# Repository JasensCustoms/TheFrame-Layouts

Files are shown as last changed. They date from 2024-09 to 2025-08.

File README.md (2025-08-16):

# TheFrame-Layouts
Layouts for JasensCustoms.com - The Frame Fight Stick

All Layouts are provided either by JasensCustoms.com or a member of the community. These are provided as-is under the GNU Public License V3.0.

# The Frame is by JasensCustoms.com - A fight stick maker since 2012.

What is The Frame? The Frame is our take on the plexi fight stick craze that has taken the Fighting Game Community by storm over the last few years. This combination Acrylic and Machined Aluminum case is not like the rest. 

jasenscustoms-theframe-chassis-1

Some Measurements that you may find useful:

- The distance between the USB Mount Center and the 24.1mm holes on either side is 60mm.



- The distance between each hole on the front is 30mm.



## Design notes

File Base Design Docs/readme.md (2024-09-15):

Welcome to THE FRAME design guide, contained within is all the important details you need for designing your custom Top Panel for THE FRAME. The files provided are for non-commercial use only. Please use them to design your layout and top panel to fit onto your new FRAME. You can submit any of the following file formats for custom cut top panels:

* DXF
* AI
* SVG

On each piece there are mounting holes and some 24mm holes for buttons. Please take the follow into consideration:

Do not remove any mounting holes (the small ones) from the side panel plexi templates.
Do not move any mounting holes. If you move them, your plexi will not attach to your FRAME properly.
You may remove the center mounting holes on the top and bottom panels if you want.
On the side plexi pieces, any of the 24mm holes can be removed if you do not intend on using those cutouts. By removing them the plexi will cover up and hide unused holes.
You can make your top panel and bottom panels larger than your FRAME and have overhang - creating some cool shapes and possibilities for your FRAME. If you add a significant amount of overhang, you may want to consider using some 51mm long support hardware to prevent flexing. There are a lot of creative ways to do this from 3D printed parts to aluminum extrusion. Just keep in mind you will need to provide mounting hole cutouts on your plexi (top, bottom, and inner pieces) to ensure you have a place to feed non-standard hardware.

**The Top and Bottom Panel has two layers.**

The outermost layer is 1.5mm and can be done with printed plexi or any of our standard colored plexi available.

The inner layer is 5mm and will be done with clear, black, or white acrylic based on your choice.

**Top Outermost layer (1.5mm):**

1. Place your buttons and joystick in an arrangement that makes sense for you. You have complete control here. Keep your layout inside of the red lines dashed lines to ensure your buttons will not hit the FRAME. You must ensure all required mounting hardware is accounted for. We will not add or alter files submitted. We cut what you send.
   
3. The Blue Dashed lines represent how far the average 24mm button will extend into the case. You can get close to these if you need to, just be advised that wiring may get tight in those areas.
   
4. If you do not want to add countersinking to the inner layer for lever builds, please ensure your mounting hardware holes for the lever you are using is on the top outer layer.
Ensure you keep the M4 mounting holes in tact on the outermost layer per the above guidelines.

The Fream Safe Area Explainer

**Top Inner Layer (5mm):**

1. Duplicate all of your cuts from the outermost layer to this inner layer.
2. You will want to create offset cuts for all of your buttons. 6.5mm is too thick for non screw in buttons to latch onto. I find that using a 40mm hole for 30mm buttons on the inner panel is sufficient for snap ins. 45mm is great for screw in buttons. (36mm for smaller 24mm buttons). You can use the centers of your top layer holes to do ensure they are perfectly aligned. Once you create them all, you can remove the button cutouts on the inner layer they won't be needed.
3. You do not and should not create offsets for any mounting hardware on this layer.
4. For a nominal fee we will countersink lever mounting hardware on your inner panel using a drill press. This is done after its laser cut to ensure perfect placement.

Example of Top Layers

This a perfect inner and outer layer. There are no extra cut lines on the inner layer. The customer used the pathfinder tool in illustrator to remove overlapping cut lines (or a power trim tool in Solidworks) to create one smooth contour cut for the inner panel. They are larger than the button holes to allow snap-ins and screw-ins to properly hold onto the 1,5mm top.

Not a good setup for top layers

This is not per the design guide. The inner and outer layers are the exact same. You will not have a solid connection with snap-ins and they may pop out. Screw-ins may work, but they wont have enough threads engaged to stay tight long term. Fix the inner layer.

**The Bottom Panel - Inner and Outer pieces**

These should be mechanically identical. If you make the bottom a different and larger shape than the rounded rectangle that is standard, just ensure both are the same. If you only submit one file for the bottom, we will cut both the 1.5mm and 5mm pieces the same. If you have a special need for the inner panel to create additional clearance, its OK to put cutlines on the inner panel. 

**Resources**

* SlagCoin - the most popular arcade layouts. http://www.slagcoin.com
* Sanwa JLF Mounting Points: 84mm x 40mm rectangle. One hole in each corner. Center hole is 24mm.
* #6-32 screw diameter: 3.51mm - use 3.6mm to be safe.
* M4 screw diameter: 4mm (metric is great) - use 4.2mm to be safe.
* 30mm buttons: use 30.1 - 30.2mm to be safe. Using an exact 30 is OK but may add stress to the body.
* 24mm buttons: use 24.1 - 24.1mm to be safe. Using and exact 24 is OK but may add stress to the body.

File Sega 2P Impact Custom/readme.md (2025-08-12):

Overszied Frame Layout (edges overhang the case by 15mm all the way around) with a custom shape requested by the customer. Features Sega 2P layout with impact button and second 24mm button at the top. Features an OLED screen mount on inner panel. Also inner cutout has a larger opening to install an LED ring (50mm diameter).

https://github.com/JasensCustoms/TheFrame-Layouts/blob/main/Sega%202P%20Impact%20Custom/customsega2P.png

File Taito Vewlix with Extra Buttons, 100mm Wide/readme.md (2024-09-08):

# Files By JasensCustoms.com
+ Created for a customer, SPAAAACE! in our discord server. Posted with their permission.
  
# Top Panel 1.5mm Outer Plexi Panel
+	The Taito vewlix layout with 100mm between the K1 button and lever
+	Main Button holes are 30mm buttons
+	A standard Japanese lever size hole on this top layer
+	A row of three 24mm buttons above the standard 30mm vewlix buttons. I’ve attached a photo as an example of the layout of these buttons

# Top Panel 5mm Inner Plexi Panel

+	Enough room underneath the buttons to accommodate screw-in buttons
+	A Korean lever-sized hole (35.1mm) for the joystick plus all mounting holes for both JP and KR levers
+	The same 7.5mm overhang on the left and right, with 2.5 mm on top and bottom. 

# Bottom Panel 5mm Inner Plexi Panel

+	A 100mm x 100mm cutout centered on the Joystick Lever to support deep Korean levers.

# Panel Size Changes

+	A 7.5mm overhang on the left and right edges, and a 2.5mm overhang on the top and bottom edges (to make the lever a little wider without getting much taller).

# Files Included
+ Top and Bottom Plexi in PSD for generating Art
+ Top and Bottom Plexi (inner and outer layers) in AI and DXF Files for remixes



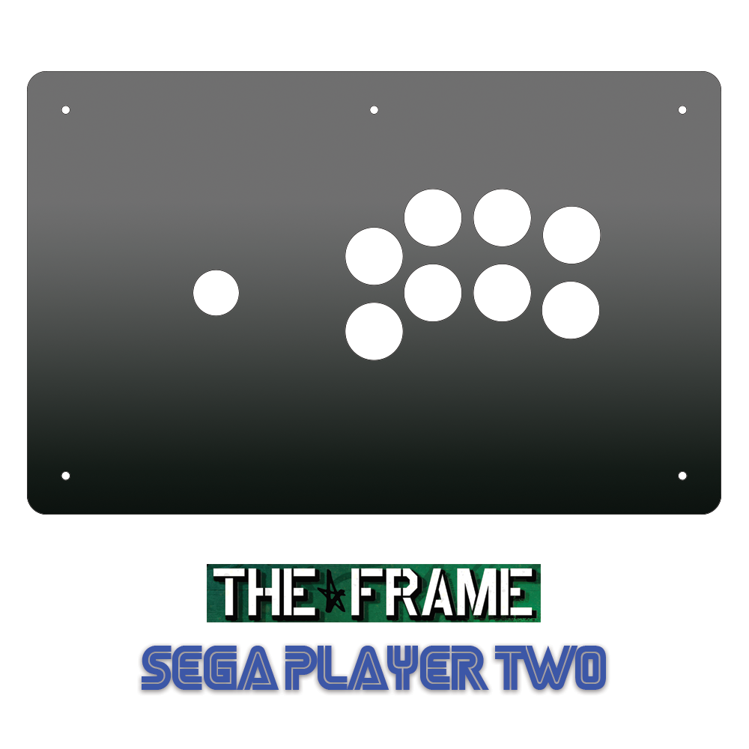
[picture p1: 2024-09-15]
Sega Player 2/Image Card.png

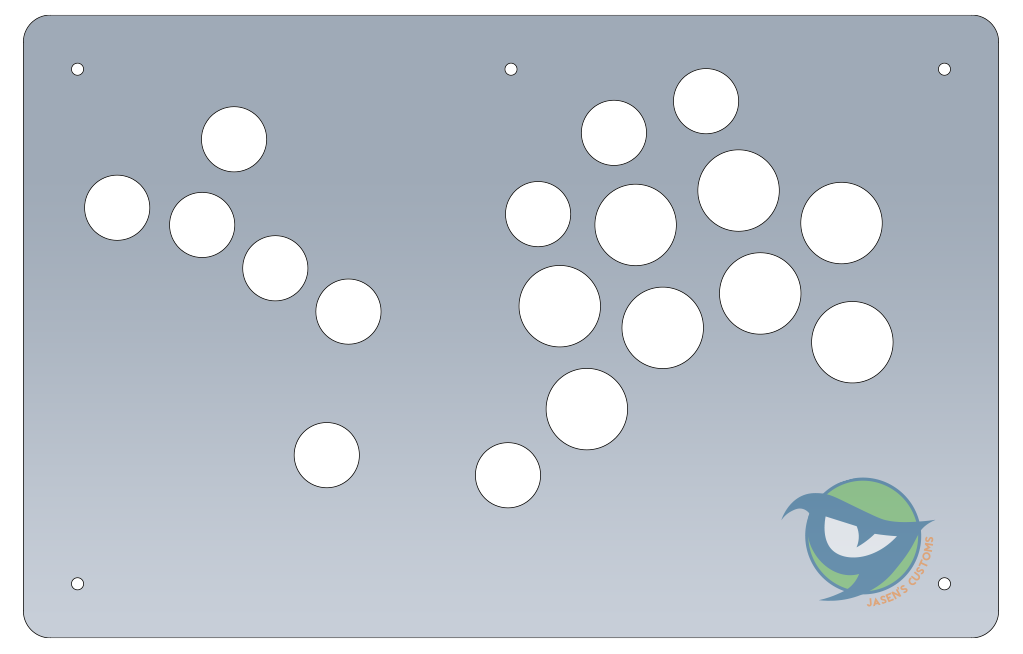
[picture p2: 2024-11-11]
Custom ABC KH Edition/CustomABC-KH.png

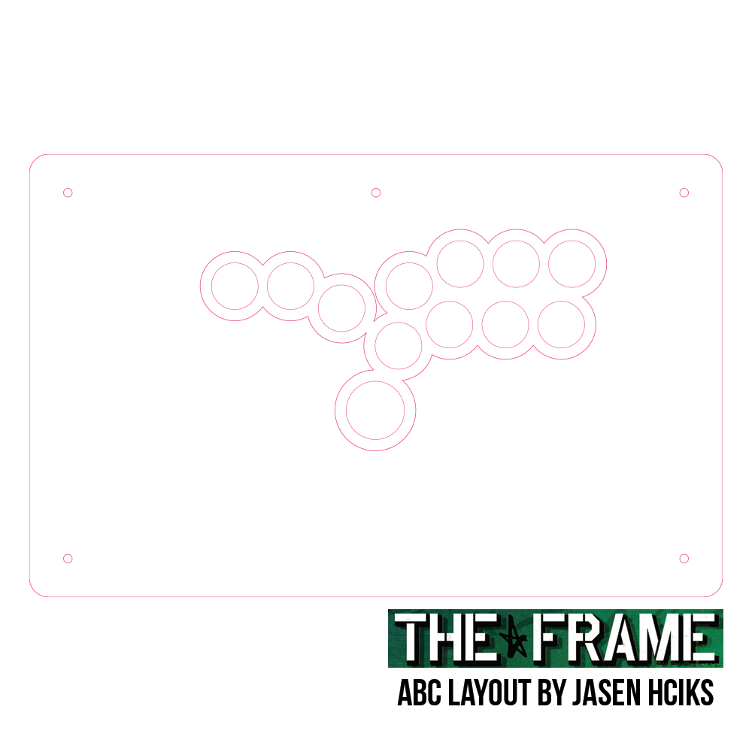
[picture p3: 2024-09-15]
All Button Controller/JasenHicks-ABC.png

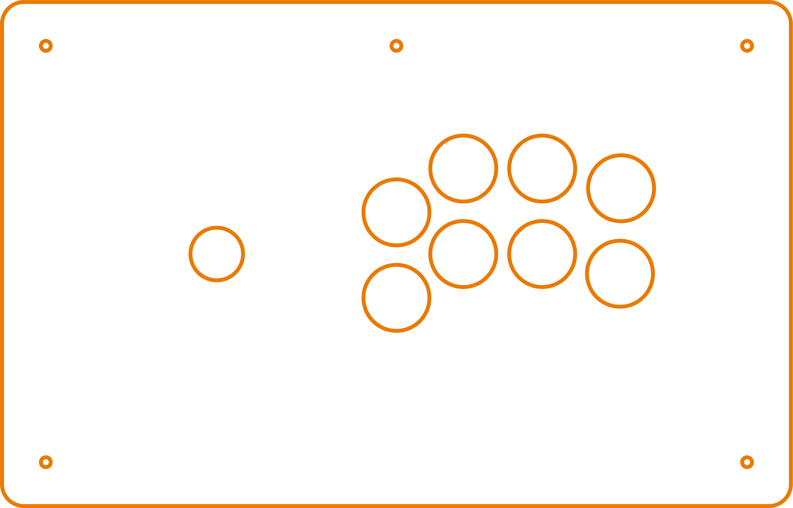
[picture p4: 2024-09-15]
Sega Player 2/JasensCustoms-TheFrame-Sega2P-82mm-Wide-OUTTER.png

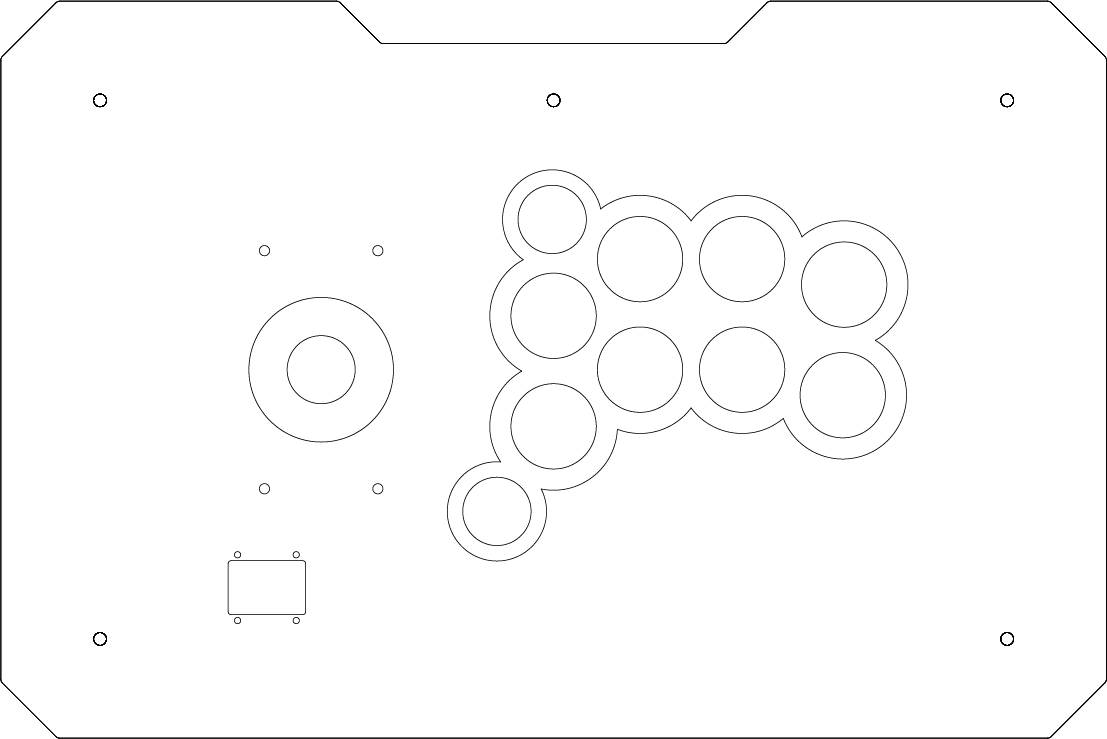
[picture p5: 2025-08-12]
Sega 2P Impact Custom/customsega2P.png

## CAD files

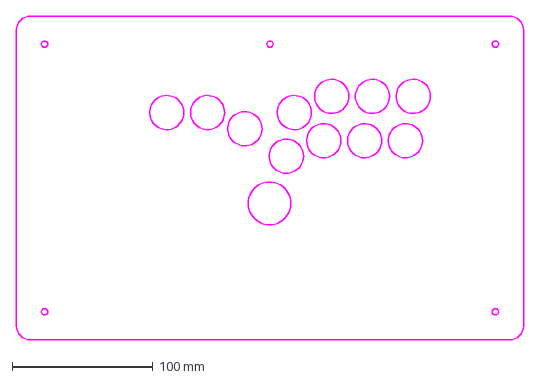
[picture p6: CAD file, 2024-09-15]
All Button Controller/JasensCustoms-ABC-Outermost.dxf
360.0 x 230.0 mm

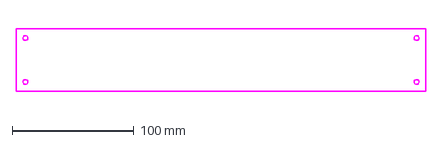
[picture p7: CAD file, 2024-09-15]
Base Design Docs/TheFrame-Back.dxf
336.0 x 51.0 mm

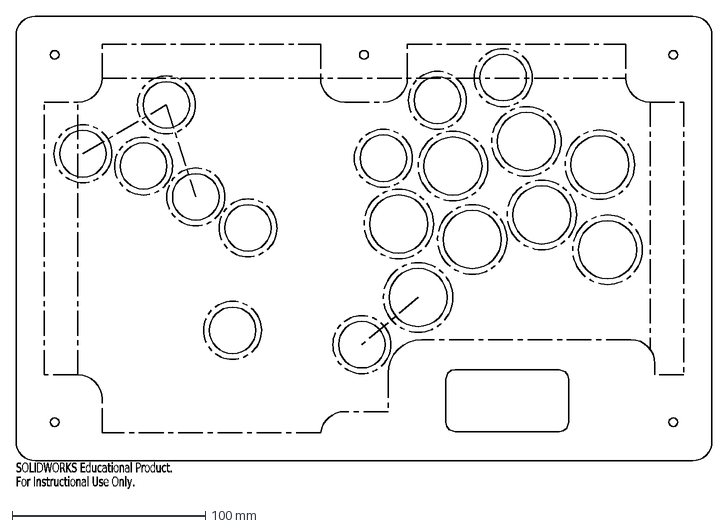
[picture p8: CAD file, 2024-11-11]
Custom ABC KH Edition/JasensCustoms-TheFrame-ABC-KH-OUTER.DXF
SOLIDWORKS Educational Product.
For Instructional Use Only.

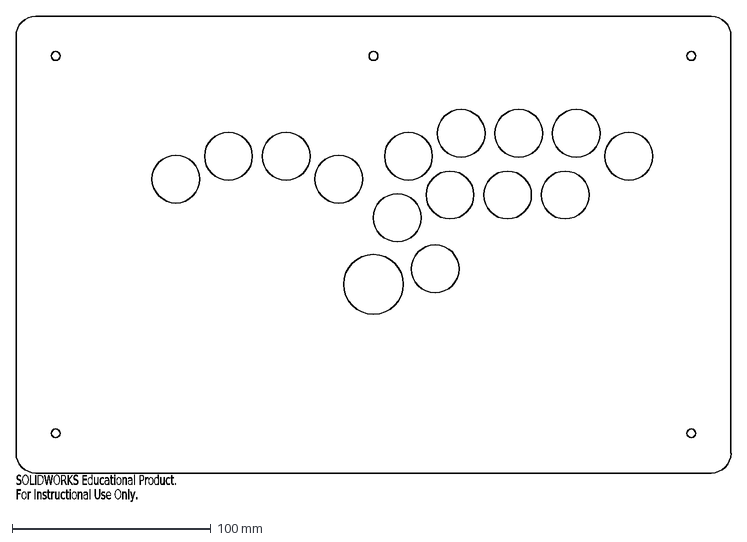
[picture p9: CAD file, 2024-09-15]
Daigo x Rageous X All Button Modern/JasensCustoms-TheFrame-DaigoInspiredABC-OUTER.DXF
SOLIDWORKS Educational Product.
For Instructional Use Only.

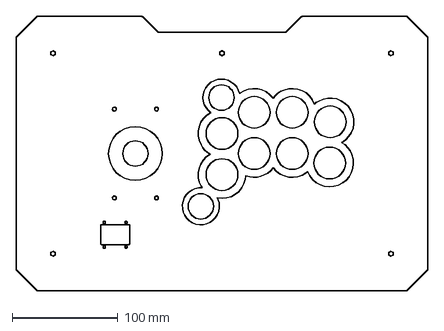
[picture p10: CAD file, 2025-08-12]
Sega 2P Impact Custom/2919 - Robert B - Layout BOTTOM.dxf
390.0 x 260.0 mm

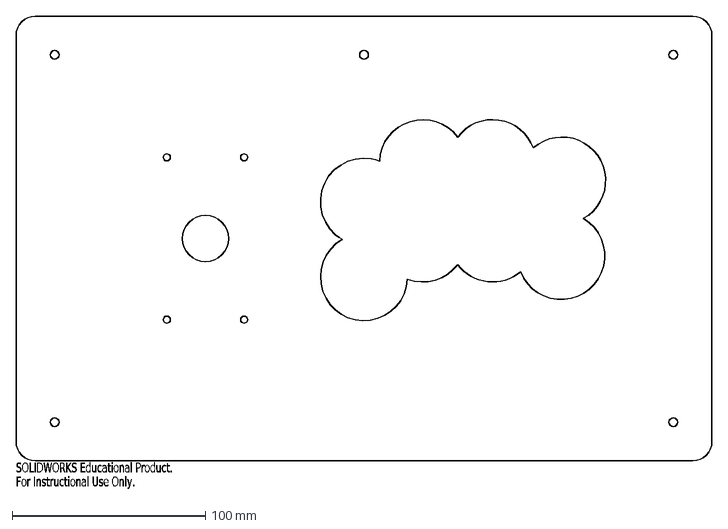
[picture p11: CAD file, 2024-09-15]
Sega Player 2/JasensCustoms-TheFrame-Sega2P-82mm-Wide-INNER.DXF
SOLIDWORKS Educational Product.
For Instructional Use Only.

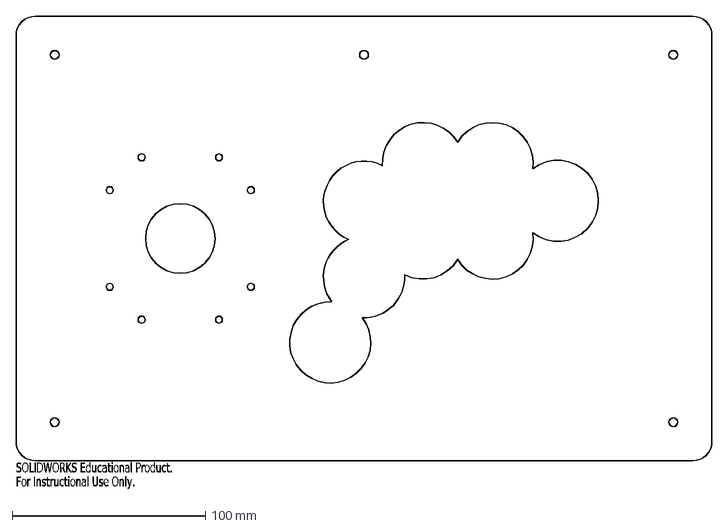
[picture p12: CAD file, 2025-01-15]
SP26M Layout/JasensCustoms-TheFrame-SP26M-Inner.DXF
SOLIDWORKS Educational Product.
For Instructional Use Only.

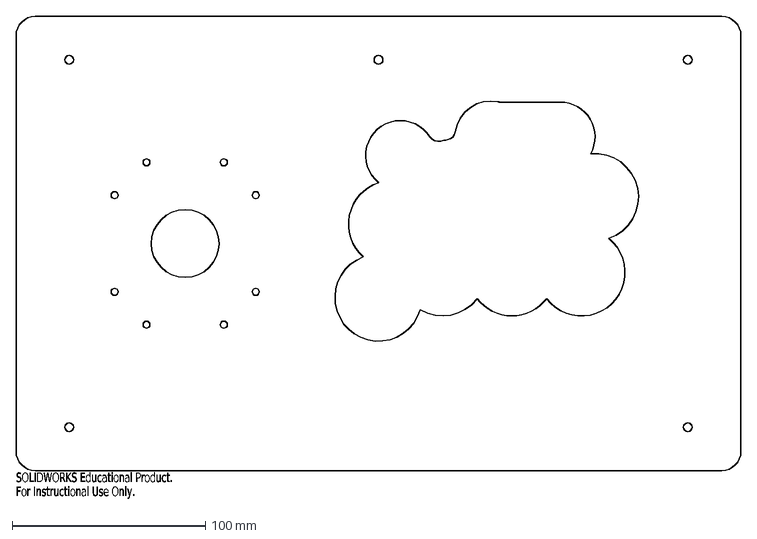
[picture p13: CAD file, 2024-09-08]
Taito Vewlix with Extra Buttons, 100mm Wide/JasensCustoms-TheFrame-TaitoVewlix Base - 100mm-Wide - Top 5.6mm.DXF
SOLIDWORKS Educational Product.
For Instructional Use Only.

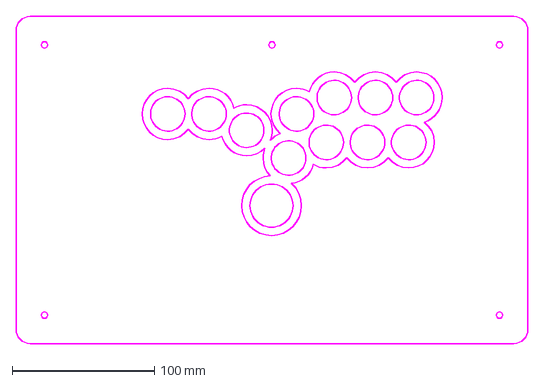
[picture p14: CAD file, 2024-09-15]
All Button Controller/JasensCustoms-ABC-Innermost.dxf
360.0 x 230.0 mm

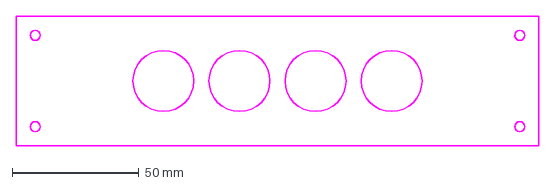
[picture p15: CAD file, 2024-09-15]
Base Design Docs/TheFrame-Short Side.dxf
206.0 x 51.0 mm

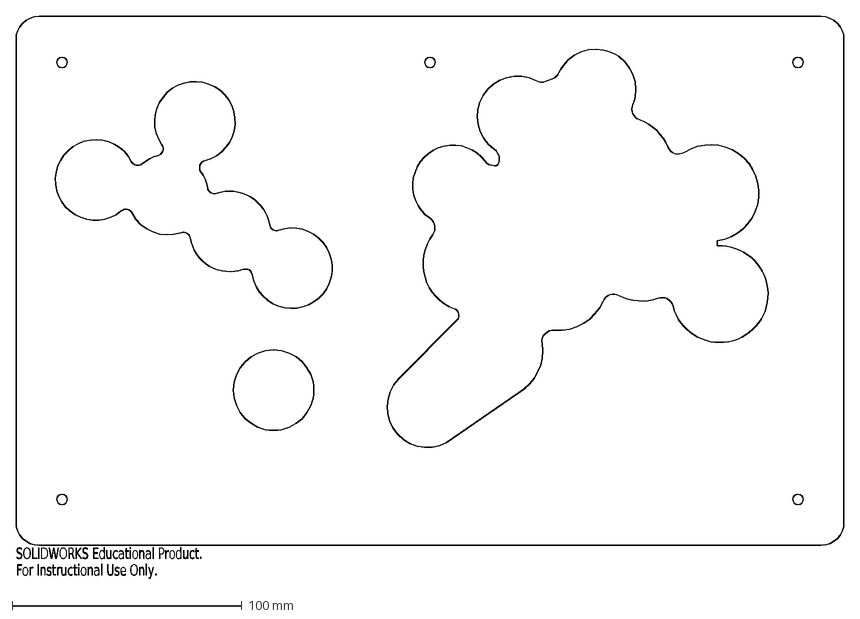
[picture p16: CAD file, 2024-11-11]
Custom ABC KH Edition/JasensCustoms-TheFrame-ABC-KH-INNER.DXF
SOLIDWORKS Educational Product.
For Instructional Use Only.

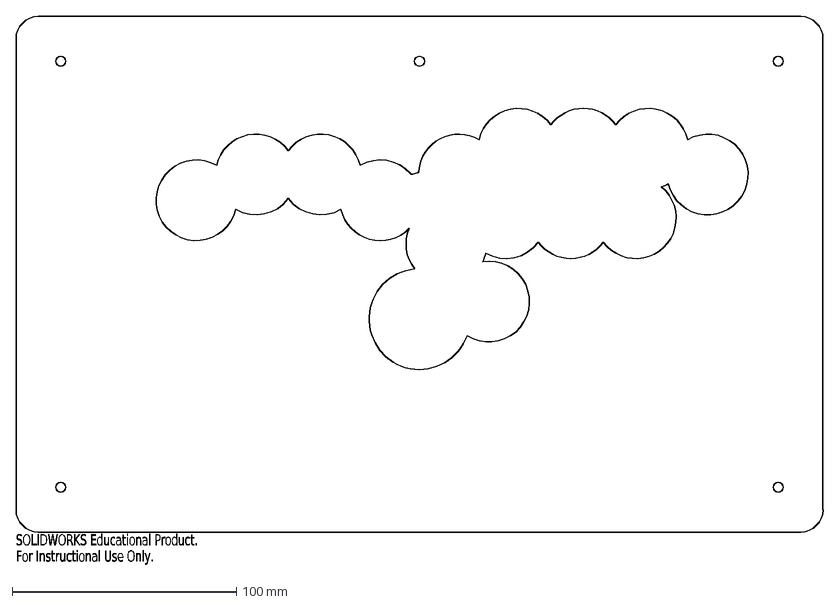
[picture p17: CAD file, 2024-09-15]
Daigo x Rageous X All Button Modern/JasensCustoms-TheFrame-DaigoInspiredABC-INNER.DXF
SOLIDWORKS Educational Product.
For Instructional Use Only.

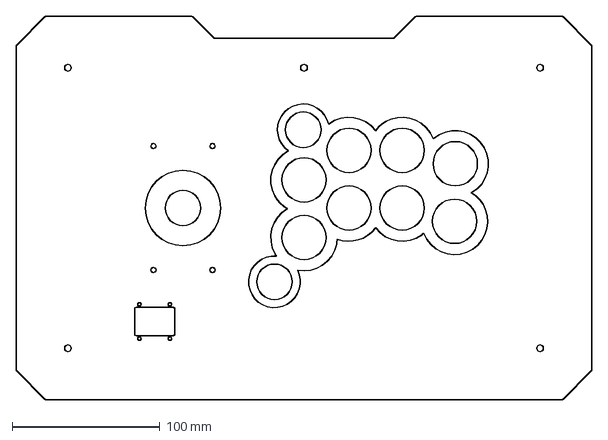
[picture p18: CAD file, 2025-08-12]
Sega 2P Impact Custom/2919 - Robert B - Layout INNER.dxf
390.0 x 260.0 mm

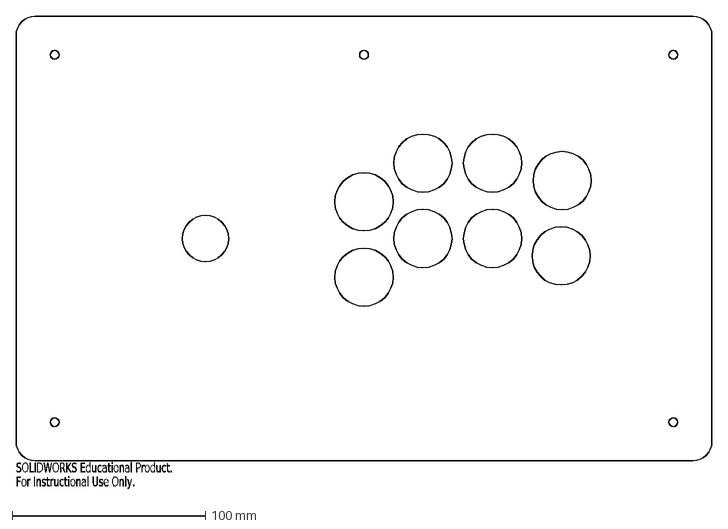
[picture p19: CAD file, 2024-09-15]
Sega Player 2/JasensCustoms-TheFrame-Sega2P-82mm-Wide-OUTTER.DXF
SOLIDWORKS Educational Product.
For Instructional Use Only.

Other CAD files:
SP26M Layout/JasensCustoms-TheFrame-SP26M-Outer.DXF
Taito Vewlix with Extra Buttons, 100mm Wide/JasensCustoms-TheFrame-TaitoVewlix Base - 100mm-Wide - Top 1.5mm.DXF
Base Design Docs/TheFrame-Front-Neutrik Behind.dxf
Sega 2P Impact Custom/2919 - Robert B - Layout OUTER.dxf
Base Design Docs/TheFrame-Bottom Area.dxf
Base Design Docs/TheFrame-Front-Neutrik Surrounded.dxf
Base Design Docs/TheFrame-Top Area.dxf
Taito Vewlix with Extra Buttons, 100mm Wide/JasensCustoms-TheFrame-TaitoVewlix Base - 100mm-Wide - Bottom 1.5mm.DXF
Taito Vewlix with Extra Buttons, 100mm Wide/JasensCustoms-TheFrame-TaitoVewlix Base - 100mm-Wide - Bottom 5.6mm.DXF

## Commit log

2024-09-15 All Button Layout for The Frame
    All Button Layout for the Frame.
    [JasensCustoms-ABC-Innermost.dxf, JasensCustoms-ABC-Outermost.dxf]
2024-09-15 Updated Layouts
    Added Sega Player 2, Daigo X Rageous X ABC
    [JasensCustoms-TheFrame-DaigoInspiredABC-INNER.DXF, JasensCustoms-TheFrame-DaigoInspiredABC-OUTER.DXF, JasensCustoms-TheFrame-Sega2P-82mm-Wide-INNER.DXF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]
2024-09-15 The Frame Base Design Documents
    Adobe Illustrator and DXF files for top, bottom, and sides of The Frame. No layout, used as a base for future layouts.
    [TheFrame-Back.dxf, TheFrame-Bottom Area.dxf, TheFrame-Front-Neutrik Behind.dxf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]
2025-08-16 Update README.md
    Added critical dimensions for hole spacing.
